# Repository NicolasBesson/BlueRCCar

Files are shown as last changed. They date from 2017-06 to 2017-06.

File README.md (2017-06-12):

# BlueRCCar
BlueRCCar is a Bluetooth RC Car driver controller solution replacing standard radio RC Car equipped with HT8A978 radio receiver, by a Bluetooth 3.0 interface. 
The addition of Bluetooth on the RC Car makes it compatible with most of the Smart Phones on the market (in 2017).

The BlueRCCar system has been mounted on a Nikko Lazer 3.

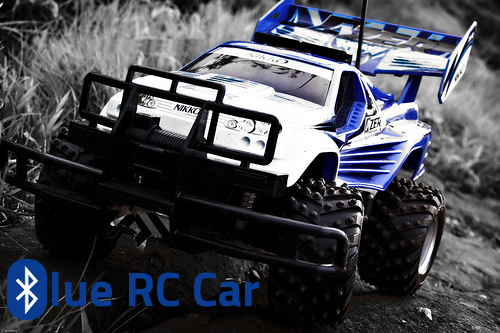
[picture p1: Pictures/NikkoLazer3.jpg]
Nikko Lazer 3


# Device Usage
The system makes the RC Car addressable via Bluetooth through an SPP (Serial Port Profile) profile using a really simplistic bidirectional protocol.

## Commands
The protocol is composed of Ascii commands that have the following meaning:

 Command | Value |  | Command | Value
------------------- | ----- | --- | ------------------- | -----
Forward             | F     |     | Extra ON            | X
Backward            | B     |     | Extra OFF           | x
Left                | L     |     | Speed 0             | 0
Right               | R     |     | Speed 10            | 1
Forward Left        | G     |     | Speed 20            | 2
Forward Right       | I     |     | Speed 30            | 3
Backward Left       | H     |     | Speed 40            | 4
Backward Right      | J     |     | Speed 50            | 5
Stop                | S     |     | Speed 60            | 6
Front Lights ON     | W     |     | Speed 70            | 7
Front Lights OFF    | w     |     | Speed 80            | 8
Rear Lights ON      | U     |     | Speed 90            | 9
Rear Lights OFF     | u     |     | Speed 100           | q
Horn ON             | V     |     | Stop All            | D
Horn OFF            | v     |     |                     | 

# Bluetooth RC Android application
The supported protocol is compatible with an existing Android application called **Arduino Bluetooth RC Car** developed by 'Andi.Co'. It is a free application and working on Android 2.3.3 and above.

## User Interface
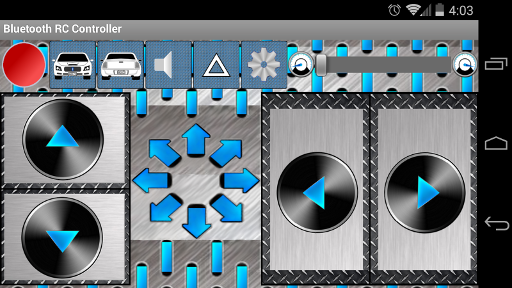
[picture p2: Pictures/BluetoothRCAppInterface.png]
Bluetooth RC Interface


# Building the Hardware
The RC Car electronic already in place is composed of two main parts, the RF Receiver that translate RF Commands into electric commands, and the motor commands through an H-Bridge.
The system is replacing the Radio Receiver, by translating Bluetooth commands into electric commands. The system is composed of three parts, the Bluetooth receiver with a USART bus, the ATtiny 85 that translates the commands and drive the last element, the GPIO Expander onto an I2C Bus.

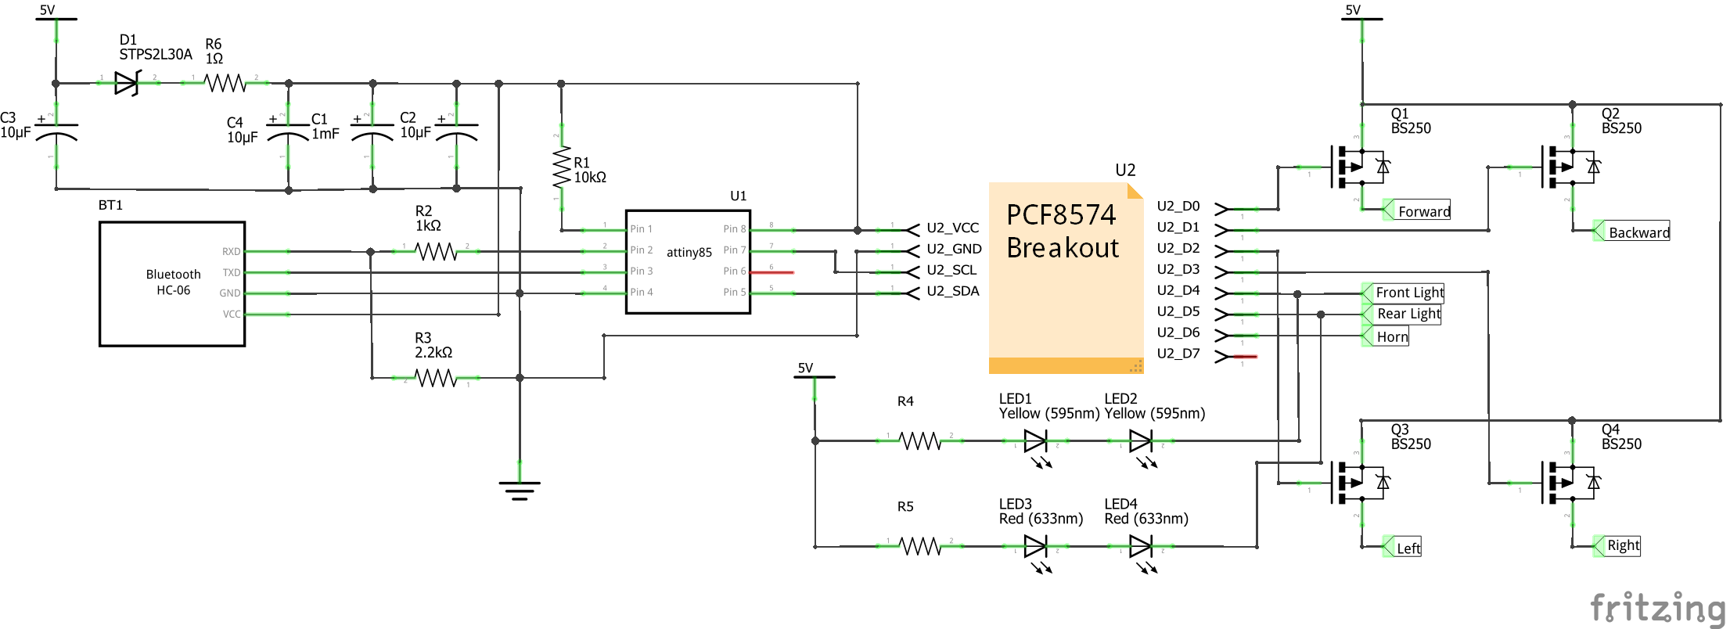
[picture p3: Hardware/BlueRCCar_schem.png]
Schematic


# Building the Software
The ATtiny 85 is a really cool Micro Controller that have 8 KB of Flash and 512 B of RAM to run any kind of C or C++ software. This gives some space to run a simple software and for this reason some optimization are required.
The project has been developed in C++ (C++11) in order to reuse and give more flexibility in case of development of new features. It is required to use the VisualMicro extension for Visual Studio 2015 in order to build the project.

## Tools
Before starting some tools are required :

* [Arduino IDE](https://www.arduino.cc/en/Main/Software)
* Visual Studio 2015 or 2017 Community Edition (and other flavors)
* [VisualMicro](http://www.visualmicro.com/) a Visual Studio plugin for Arduino development
* USBTinyISP programmer

Install Visual Studio 2015 or 2017, and make sure to select the support for C++ (Visual C++) during installation.

Install the Arduino IDE application, and launch the application. You first need to add the support of the ATtiny family as by default only Arduino based platforms are supported. From the File menu, select the Preferences submenu, and then find the “Additional Boards Manager URLs” field near the bottom of the dialog. Add the following url: https://raw.githubusercontent.com/damellis/attiny/ide-1.6.x-boards-manager/package_damellis_attiny_index.json
You can then validate and close the preferences dialog box. Then from the Tools menu you have to :

* Select the Board entry and choose **Board Manager** to add ATtiny board support.
* Select **ATtiny** as Board
* Select **ATtiny85** as Processor
* Select **16MHz (Internal)** as Clock or **8MHz (Internal)** as Clock
* Select **USBtinyISP** as Programmer

## Project Dependencies
The project depends on the following libraries:

* **SoftwareSerial** by Peter Lerup revision 1.0.0
* **TinywireM** by Adafruit

In oder to be able to build the software all the dependencies need to be installed as following from Arduino IDE application :
* From the **Sketch** menu select the **Include Library**
* Select **Manage Libaries ...** from the list
* Search the library name using the search area 
* Install it using the **install** button.

## VisualMicro configuration

Close the **Arduino IDE** application and install the Visual Micro plugin for Visual Studio.
Launch **Visual Studio** and open the BlinkyBike.sln from the project folders.
On first usage of Visual Micro, you have to configure the various parameters of the plugin.

* Select the version of the IDE you select
* Enter the path to the tool installation folder

Then validate the configuration window and access the Visual Studio IDE. From vMicro menu:

* Select **ATtiny w/ ATtiny85** as Board
* Select **Internal 16MHz** or **Internal 8MHz** as Option2 (based on the Fuse configuration applied under Arduino IDE
* Select **USBtinyISP** as Programmer

The development environment is now ready for building and flashing.

## Compilation
The source code compiles in Visual Studio 2015 using the VisualMicro plugin and Arduino IDE (cf Tools chapter for installation details).
To compile the project you have to :

* Open the BlueRCCar\BlueRCCar.sln solution file
* From Visual Studio, select **Build** menu and choose **Configuration Manager** entry
* From the Configuration Manager window, select **Release** in the **Active solution configuration** drop box
* Click on the Close button to close the Configuration Manager window
* From **Build** menu select **Build Solution** entry
* Wait few seconds (usually less than 30 seconds)
* Ensure that the last output from the Output window is : *Program size: 5,476 bytes (used 67% of a 8,192 byte maximum) (17.83 secs)* (values may vary)

Then you are ready to program your ATtiny 85.

## Programming
The ATtiny 85 micro controller can be programmed using the USBTinyISP programmer. The programmer is visible through a serial com port. You need to identify the associate port index (using Windows Device Manager) in order configure the Visual Micro plugin. 

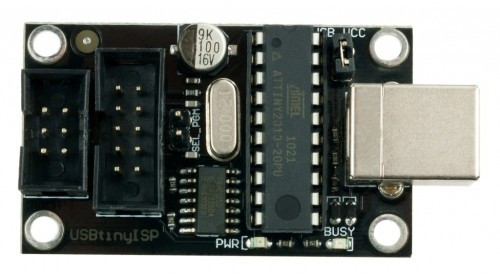
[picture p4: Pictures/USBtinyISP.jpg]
USB Tiny ISP


You need to wire the programmer as following:

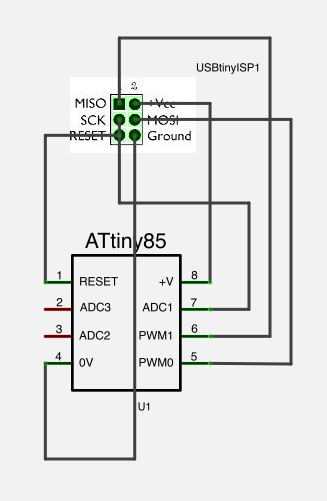
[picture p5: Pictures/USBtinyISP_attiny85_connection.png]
USB Tiny ISP with ATtiny85


# Assembling

## Original RF Main board

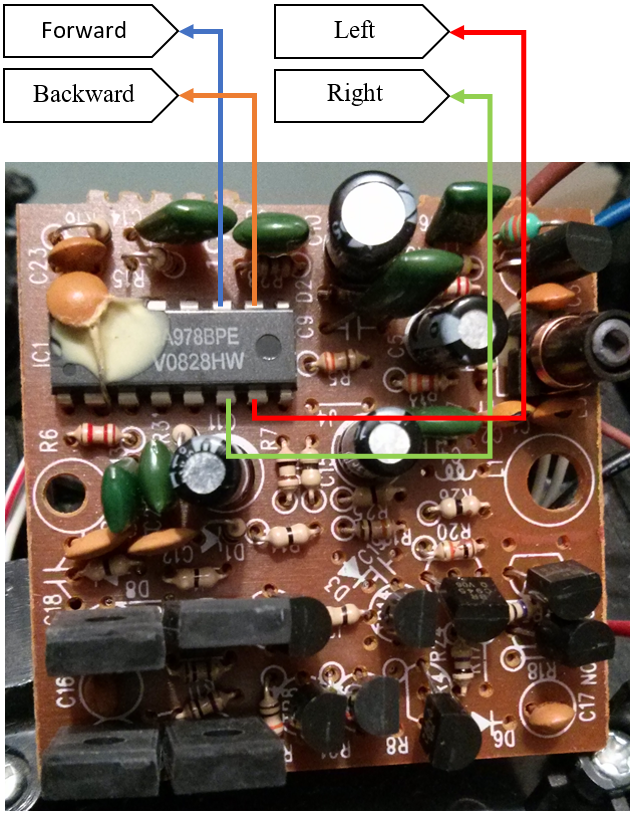
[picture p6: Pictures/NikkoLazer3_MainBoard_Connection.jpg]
RF Main Board interface


# Revision History
## V1.0 - 2017-06-10
* Initial release of the Firmware and Hardware
* Supported features
  * Forward, Backward, Left Right
* Untested features
  * Light

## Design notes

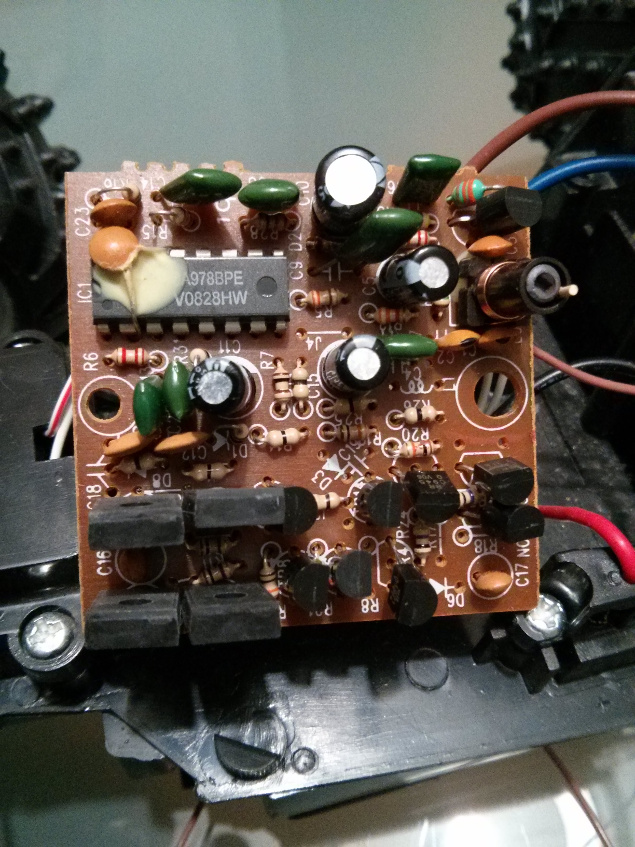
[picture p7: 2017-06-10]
Pictures/NikkoLazer3_MainBoard.jpg

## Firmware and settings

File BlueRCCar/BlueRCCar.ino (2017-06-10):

/////////////////////////////////   License  //////////////////////////////////
///////////////////////////////////////////////////////////////////////////////
// Copyright 2017 Nicolas BESSON - BeeAtHome
//
// Licensed under the Apache License, Version 2.0 (the "License");
// you may not use this file except in compliance with the License.
// You may obtain a copy of the License at
//
//     http://www.apache.org/licenses/LICENSE-2.0
//
// Unless required by applicable law or agreed to in writing, software
// distributed under the License is distributed on an "AS IS" BASIS,
// WITHOUT WARRANTIES OR CONDITIONS OF ANY KIND, either express or implied.
// See the License for the specific language governing permissions and
// limitations under the License.
//
///////////////////////////////////////////////////////////////////////////////

/******************************************************************************
 *               ____  _              _____   _____ _____
 *              |  _ \| |            |  __ \ / ____/ ____|
 *              | |_) | |_   _  ___  | |__) | |   | |     __ _ _ __
 *              |  _ <| | | | |/ _ \ |  _  /| |   | |    / _` | '__|
 *              | |_) | | |_| |  __/ | | \ \| |___| |___| (_| | |
 *              |____/|_|\__,_|\___| |_|  \_\\_____\_____\__,_|_|
 *                                                  Version 1.0
 *
 ******************************************************************************/

#include <SoftwareSerial.h>
#include "Protocol.h"
#include "RCDriver.h"

/*
 * ATTiny 85 pinout
 *
 *          +-\/-+
 * A0 PB5  1|    |8  Vcc
 * A3 PB3  2|    |7  PB2 D0 A1
 * A2 PB4  3|    |6  PB1 D1
 *    GND  4|    |5  PB0 D2
 *          +----+
 */

#define PIN_BLUETOOTH_RX		PB3
#define PIN_BLUETOOTH_TX		PB4
#define PIN_BLUETOOTH_STATE		PB1
#define PIN_PCF8564_SDA			PB0
#define PIN_PCF8564_SCL			PB2

//
SoftwareSerial bluetoothSerial(PIN_BLUETOOTH_TX, PIN_BLUETOOTH_RX); // RX, TX
Protocol bluetoothProtocol;
RCDriver rcDriver;

void setup()
{
	// Configure PIOs
	pinMode(PIN_BLUETOOTH_STATE, INPUT);

	// Enable Bluetooth Serial
	bluetoothSerial.begin(9600);

	// Enable rcDriver
	rcDriver.begin();
}

void loop()
{
	int data = 0x00;

	// Data available from Bluetooth Serial
	if (bluetoothSerial.available() > 0)
	{
		// Read the data
		data = bluetoothSerial.read();

		// Decode the protocol
		bluetoothProtocol.command((unsigned char)data);
	}
	else
	{

	}

	// Update driver based on received protocol
	rcDriver.setState(bluetoothProtocol.getState());
	rcDriver.enableExtra(bluetoothProtocol.isExtraEnabled());
	rcDriver.setSpeed(bluetoothProtocol.getSpeed());

	rcDriver.run();
}

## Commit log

2017-02-16 Initial Schematic
    [BlueRCCar.fzz]
2017-02-19 Fixing PCF8574 I2C device address
    Moving from 0x40 to 0x38 (PCF8574A device)
    Defines all acceptable addresses for PCF8574 and PCF8574A devices
2017-03-27 Inverting the Forward and Backward logic for electrical command
    [BlueRCCar.fzz]
2017-03-28 Updating documentation by adding RF Main Board picture
2017-05-30 Schematic update for electrical incompatibility
    [BlueRCCar.fzz]
